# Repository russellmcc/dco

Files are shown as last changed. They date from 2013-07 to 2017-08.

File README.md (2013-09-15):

This is a simple design for an incredibly cost-sensitive DCO module for eurorack format modular synthesizers.

Firmware was written with Arduino, using @brendan0powers's [Xmegaduino fork](https://github.com/brendan0powers/Xmegaduino).  To program, use the following avrdude command from the `firmware` directory, using an [avrismpmkII](http://www.atmel.com/tools/AVRISPMKII.aspx):

    avrdude -patxmega32a4 -cavrispmkII -Pusb -Uflash:w:firmware.hex

This work is licensed under a [Creative Commons Attribution-ShareAlike 3.0 Unported License.](http://creativecommons.org/licenses/by-sa/3.0/deed.en_US)

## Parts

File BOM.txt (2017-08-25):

Connectors:
1x MO4x2         Connection header
1x M04x2  female Connection jack
1x MO3x2     AVR PDI header
1x MO8x2     Eurorack power connector
3x erthenvar jacks

Semiconductors
1x QFP44     Atmel XMega 32A4U (TQFP)         (U1)
1x SOT23     MMBT3904 NPN Transistor          (Q101)
1x SOT223    MIC2920A-3.3BS regulator         (IC301)
2x SOIC-8    LF353D op amp                    (IC101, IC201)
2x SOD-323   5V zener diode                   (D301, D301)

Potentiometers
3x PDB12 100K PCB mount panel pot (PDB12-H4251-104BF)
1x 5mm   100K thru-hole trimpot (N6-L50T0C-100K)

Resistors
1x 0805 1    Resistor 5% (R102)
1x 0603 1K   Resistor 5% (R110)
5x 0603 10K  Resistor 5% (R101, R107, R108, R301, R302)
1x 0603 27K  Resistor 5% (R205)
1x 0603 33K  Resistor 5% (R208)
1x 0603 33K  Resistor 1% (R209)
1x 0603 51K  Resistor 1% (R207)
5x 0603 100K Resistor 5% (R104, R105, R202, R203, R206)
1x 0603 100K Resistor 1% (R201)
1x 0603 200K Resistor 5% (R103)
1x 0603 300K Resistor 5% (R109)
1x 0603 1M   Resistor 5% (R106)
1x 0603 1.5M Resistor 5% (R204)

Capacitors
1x 0603 220pF C0G capacitor      (C101)
3x 0603 .1uF  X7R capacitor      (C302, C303, C305)
1x 1210 .1uF  PPS capacitor      (C102)
2x 0805 1uF   X7R capacitor      (C103, C301) 
1x 1205 10uF  X5R capacitor      (C304)

Other TODOs- 
Make sure C103 does not have too much distortion during testing

Mouser link to project:
http://www.mouser.com/ProjectManager/ProjectDetail.aspx?AccessID=DEDAD2A673

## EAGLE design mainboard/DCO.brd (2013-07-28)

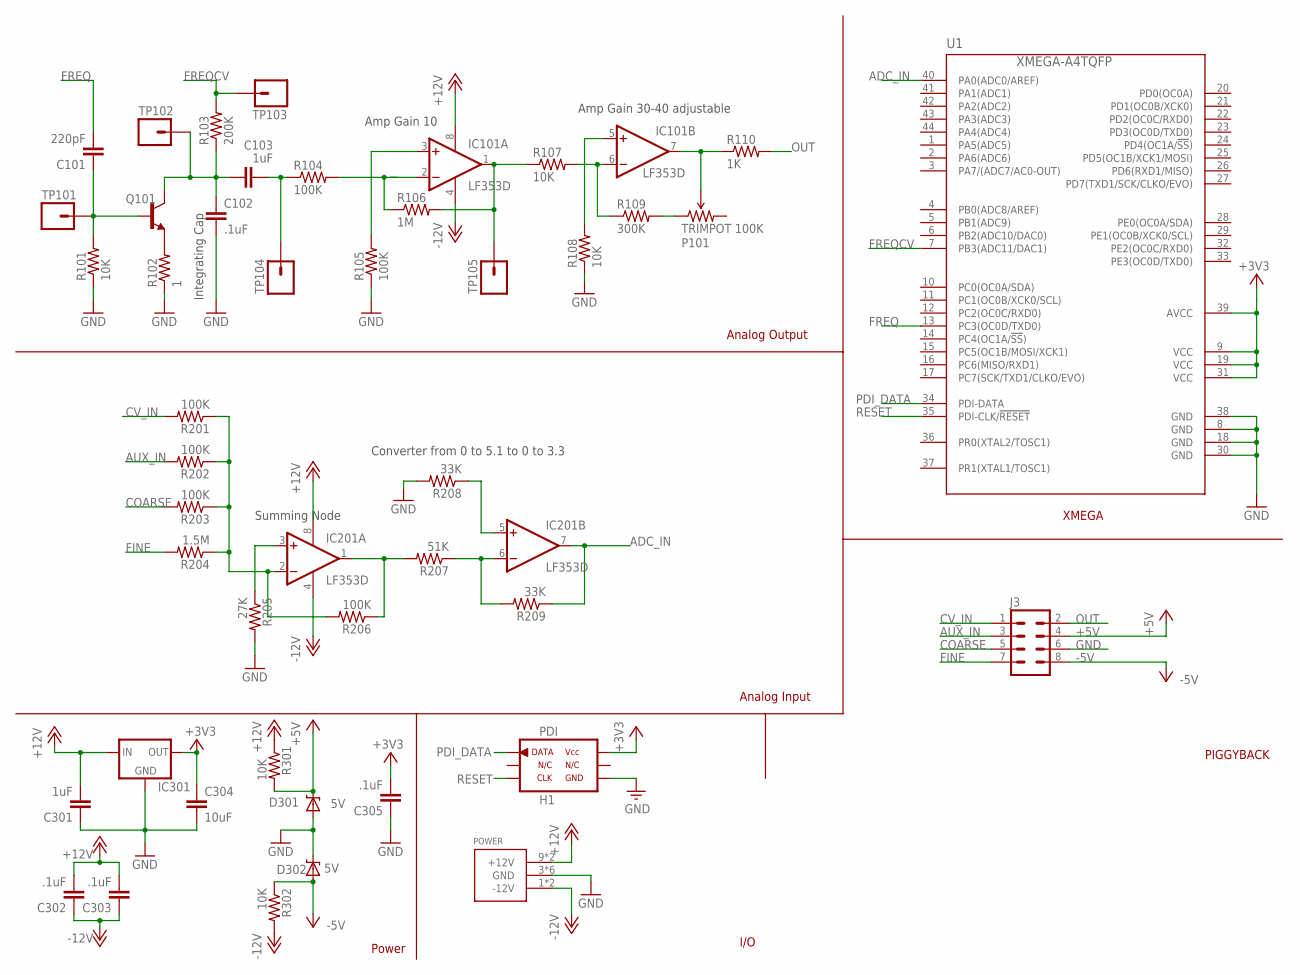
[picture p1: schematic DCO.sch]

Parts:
C101: 220pF; 0603-CAP
C102: .1uF; 1210
C103, C301: 1uF; 0805
C302, C303, C305: .1uF; 0603-CAP
C304: 10uF; 1206
D301, D302: 5V; SOD-323
H1: PDI; AVR_ISP_6
IC101, IC201: LF353D; SO08
IC301: V_REG_MIC2920; SOT223
J3: M04X2; 2X4
P101: TRIMPOT 100K; TRIM_POT_PTH
POWER: POWER_SIMPLE16; POWER_16
Q101: TRANSISTOR_NPNSOT23; SOT23
R101, R107, R108, R301, R302: 10K; 0603-RES
R102: 1; 0805
R103: 200K; 0603-RES
R104, R105, R201, R202, R203, R206: 100K; 0603-RES
R106: 1M; 0603-RES
R109: 300K; 0603-RES
R110: 1K; 0603-RES
R204: 1.5M; 0603-RES
R205: 27K; 0603-RES
R207: 51K; 0603-RES
R208, R209: 33K; 0603-RES
TP101, TP102, TP103, TP104, TP105: M01PTH; 1X01
U1: XMEGA-A4TQFP; TQFP44

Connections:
+3V3: C304.1, C305.2, H1.P$2 (VCC_IO), IC301.3 (OUT), U1.9 (VCC), U1.19 (VCC), U1.31 (VCC), U1.39 (AVCC)
+5V: D301.1 (C), J3.4, R301.2
+12V: C301.2, C302.2, C303.2, IC101.8 (V+), IC201.8 (V+), IC301.1 (IN), POWER.9 (+12V), POWER.10 (+12V), R301.1
-5V: D302.2 (A), J3.8, R302.1
-12V: C302.1, C303.1, IC101.4 (V-), IC201.4 (V-), POWER.1 (-12V), POWER.2 (-12V), R302.2
ADC_IN: IC201.7 (OUT), R209.1, U1.40 (PA0(ADC0/AREF))
AUX_IN: J3.3, R202.2
COARSE: J3.5, R203.2
CV_IN: J3.1, R201.2
FINE: J3.7, R204.2
FREQ: C101.2, U1.13 (PC3(OC0D/TXD0))
FREQCV: R103.2, TP103.1, U1.7 (PB3(ADC11/DAC1))
GND: C102.2, C301.1, C304.2, C305.1, D301.2 (A), D302.1 (C), H1.P$6 (GND), IC301.2 (GND), J3.6, POWER.3 (GND), POWER.4 (GND), POWER.5 (GND), POWER.6 (GND), POWER.7 (GND), POWER.8 (GND), R101.1, R102.1, R105.1, R108.1, R205.2, R208.2, U1.8 (GND), U1.18 (GND), U1.30 (GND), U1.38 (GND)
unnamed: C102.1, C103.1, Q101.3 (C), R103.1, TP102.1
unnamed: C101.1, Q101.1 (B), R101.2, TP101.1
unnamed: IC101.6 (-IN), R107.2, R109.1
unnamed: Q101.2 (E), R102.2
unnamed: C103.2, R104.1, TP104.1
unnamed: IC201.3 (+IN), R205.1
unnamed: IC101.3 (+IN), R105.2
unnamed: IC101.5 (+IN), R108.2
unnamed: IC101.7 (OUT), P101.2 (WIPER), R110.1
unnamed: P101.1 (CCW), R109.2
unnamed: IC101.1 (OUT), R106.2, R107.1, TP105.1
unnamed: IC201.1 (OUT), R206.1, R207.2
unnamed: IC201.6 (-IN), R207.1, R209.2
unnamed: IC201.5 (+IN), R208.1
OUT: J3.2, R110.2
PDI_DATA: H1.P$1 (DATA), U1.34 (PDI-DATA)
R104: IC101.2 (-IN), R104.2, R106.1
R205: IC201.2 (-IN), R201.1, R202.1, R203.1, R204.1, R206.2
RESET: H1.P$5 (CLK), U1.35 (PDI-CLK/!RESET)

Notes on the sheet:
Integrating Cap
Amp Gain 10
Amp Gain 30-40 adjustable
Summing Node
Converter from 0 to 5.1 to 0 to 3.3
Analog Output
Analog Input
Power
I/O
XMEGA
PIGGYBACK

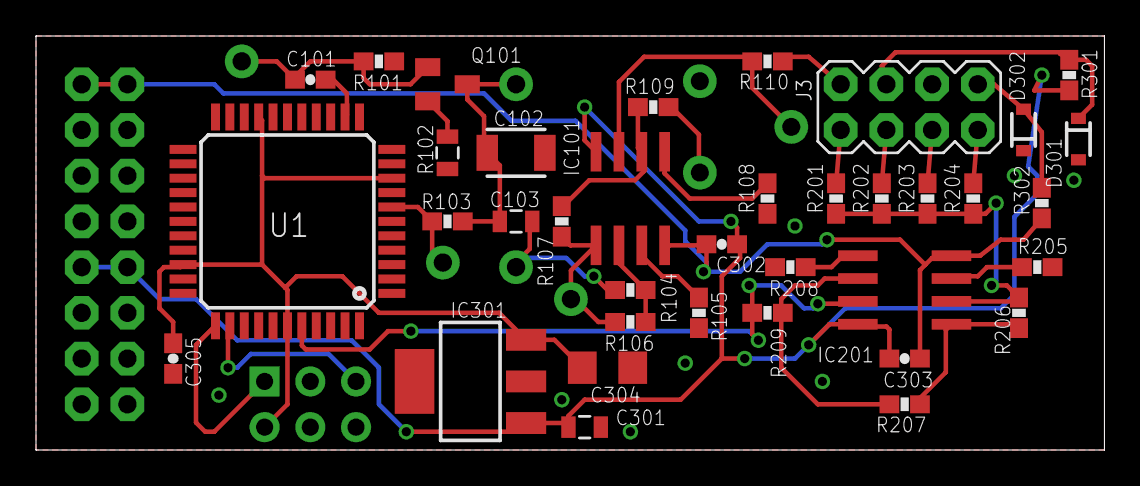
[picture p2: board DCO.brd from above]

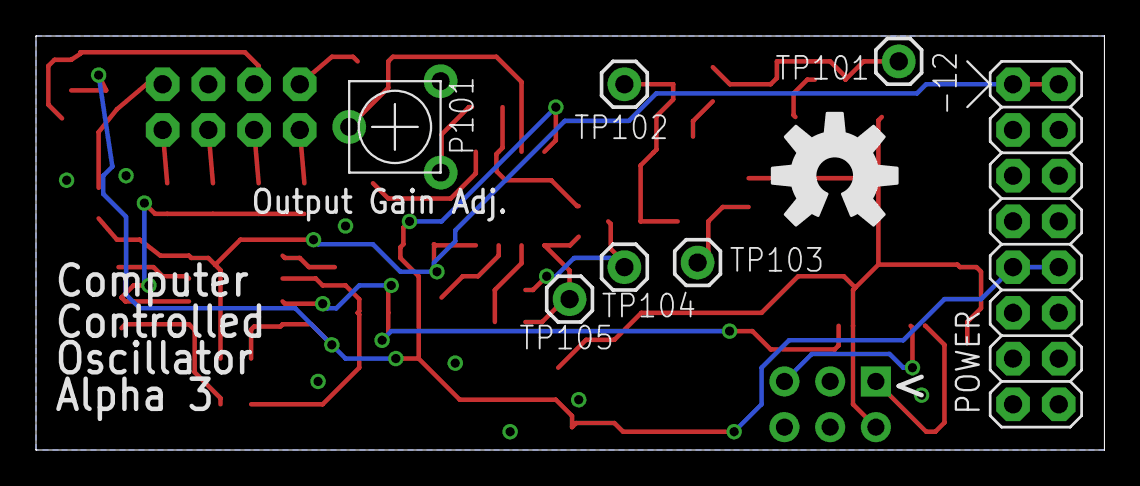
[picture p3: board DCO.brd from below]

Board: 2 copper layers, 59.4 x 23.0 mm, 46 parts (9 on the bottom side), 32 nets.

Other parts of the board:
U$1: OSHW-LOGO-L

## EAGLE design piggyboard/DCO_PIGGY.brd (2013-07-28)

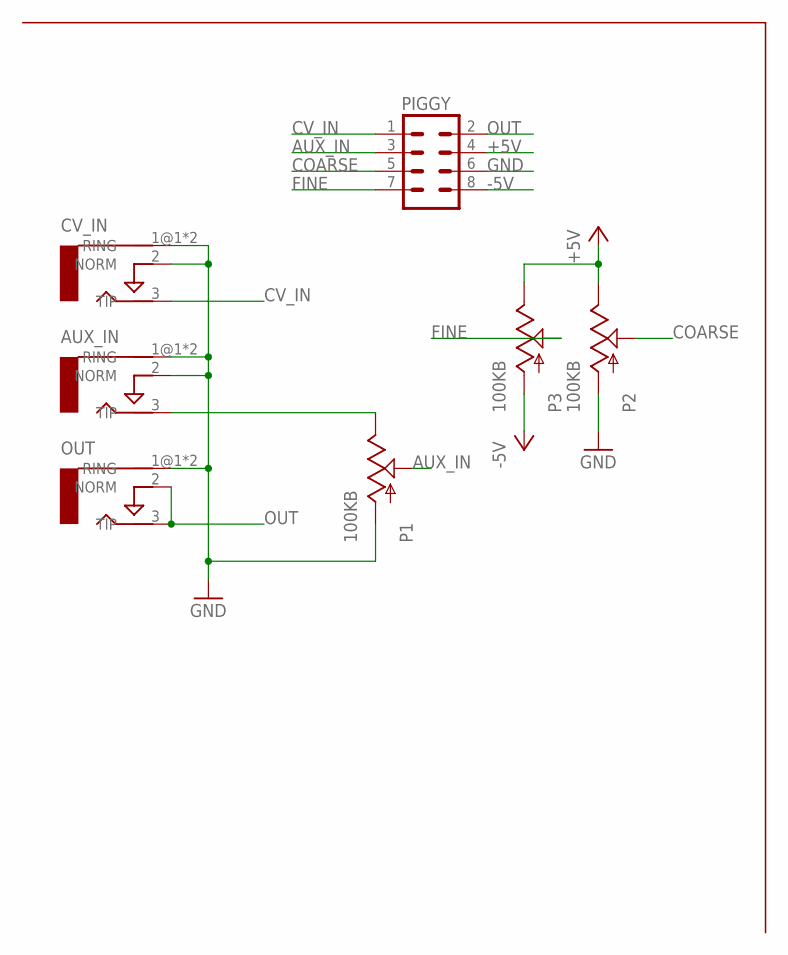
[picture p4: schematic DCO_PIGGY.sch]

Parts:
AUX_IN: AUDIO-JACKERTHENVAR; ERTHENVAR-JACK
CV_IN: AUDIO-JACKERTHENVAR; ERTHENVAR-JACK
OUT: AUDIO-JACKERTHENVAR; ERTHENVAR-JACK
P1, P2, P3: 100KB; PDB12
PIGGY: M04X2; 2X4

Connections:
+5V: P2.3 (E), P3.3 (E), PIGGY.4
-5V: P3.1 (A), PIGGY.8
AUX_IN: P1.2 (S), PIGGY.3
COARSE: P2.2 (S), PIGGY.5
CV_IN: CV_IN.3 (TIP), PIGGY.1
FINE: P3.2 (S), PIGGY.7
GND: AUX_IN.1@1 (RING), AUX_IN.1@2 (RING), AUX_IN.2 (NORM), CV_IN.1@1 (RING), CV_IN.1@2 (RING), CV_IN.2 (NORM), OUT.1@1 (RING), OUT.1@2 (RING), P1.1 (A), P2.1 (A), PIGGY.6
unnamed: AUX_IN.3 (TIP), P1.3 (E)
OUT: OUT.2 (NORM), OUT.3 (TIP), PIGGY.2

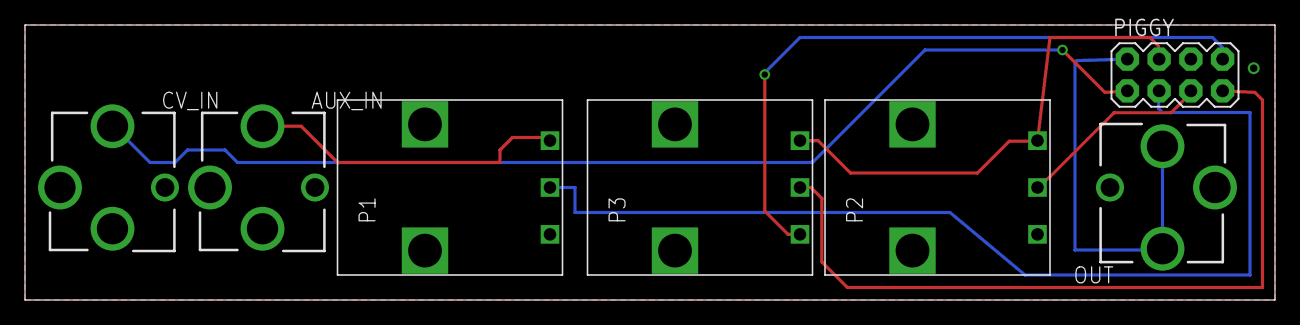
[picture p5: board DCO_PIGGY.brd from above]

Board: 2 copper layers, 100.0 x 22.0 mm, 7 parts (0 on the bottom side), 9 nets.

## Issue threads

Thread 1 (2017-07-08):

Still relevent?

dwhacks, 2017-07-08:
How does this project work? Im looking for a DIY DCO project for my eurorack and stumbled upon this but noticed its a bit older. Are you happy with it? should I get the boards fabbed and build a couple up?

russellmcc, 2017-07-08:
Great question!  I would say I am not happy with this iteration of the design.  It seems to be *very* sensitive to power supply fluctuations.  I'm actually hoping to return to this project this year to fix it up for switching power supplies.  It did work great when I had an expensive linear supply, though.

If you have some analog chops, I'd definitely be open to help cleaning up the analog path for better power supply rejection.  I think the digital code and DCO core is pretty solid.

I'm not aware of another juno 6/60/106-style DCO DIY eurorack project.  I'm currently working on an alpha juno "DCO" (works with direct digital synthesis at 6MHz for lower aliasing), which should be done in a few months.

You might want to look at the mutable instrument braids or the "microbraids" OLED variant if you're looking for a digital/analog DIY project - of course this isn't the same as the juno-style DCO, though.

dwhacks, 2017-07-08:
Thanks!
I have looked at the microbraids and also the Neutron Orgone Accumulator as options, but this one peaked my interest more being smaller and more unique (in my opinion).

Im not sure what you mean by "analog chops".

russellmcc, 2017-07-08:
I just meant "ability to do analog design well" :-)

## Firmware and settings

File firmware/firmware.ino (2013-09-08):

#include "MultiTone.h"
#include "stdint.h"
#include "table.h"

uint32_t running_average; //1.15 format

// optional lowpass filter
const float alphaFloat = 0;  // CHANGE THIS TO ADD PORTAMENTO/TUNING STABILITY.
                             // higher the value, more portamento and more stability.
const uint32_t alpha = 0xFFFF * alphaFloat; //0.16
const uint32_t oneMinusAlpha = 0xFFFF * (1 - alphaFloat); //0.16

// we need 12 bits of ADC
extern "C" int analogRead12(unsigned char pin);

void EnableDFLL()
{
  // enable the 32KHz clock
  OSC.CTRL |= OSC_RC32KEN_bm;

  // wait for stability
  while(not (OSC.STATUS & OSC_RC32KRDY_bm));

  // enable DFLL for extra power drain and accuracy.
  OSC.DFLLCTRL = (OSC.DFLLCTRL & ~OSC_RC32MCREF_gm) | OSC_RC32MCREF_RC32K_gc;
  DFLLRC32M.CTRL |= DFLL_ENABLE_bm;
  
  // wait for 32MHz stability.
  while(not (OSC.STATUS & OSC_RC32MRDY_bm));
}

void SetupTimers()
{
  // TCC1 is the prescaler timer, triggering events on EVCH6
  TCC1.CTRLA = TC_CLKSEL_DIV1_gc;
  TCC1.CTRLB = (TCC1.CTRLB & ~TC0_WGMODE_gm) | TC_WGMODE_SINGLESLOPE_gc;
  TCC1.PERBUF = 0x3; // every fourth clock
  
  // set it up to trigger EVCH6 events whenever TCC1 overflows
  EVSYS.CH6MUX = EVSYS_CHMUX_TCC1_OVF_gc;
  
  // TCC0D is the output timer (pin D13)
  pinMode(13, OUTPUT);
  TCC0.CTRLA = TC_CLKSEL_EVCH6_gc;
  TCC0.CTRLB = (TCC0.CTRLB & ~TC0_WGMODE_gm) | TC_WGMODE_SINGLESLOPE_gc;
  TCC0.CTRLB |= TC0_CCDEN_bm;
  TCC0.PERBUF = 0x8FFF; // half-way
  TCC0.CCDBUF = 10;
}

void setup()
{
  // use the arduino library calls to 
  // get everything into the right mode
  // we'll later use the setup done here
  // to just do fast writes to the underlying registers.
  analogWrite(A0, 12);
  EnableDFLL();
  SetupTimers();
  running_average = analogRead12(8) << 3; //1.15
}

void UpdateTimers(uint16_t input)
{
  uint16_t preScale = pgm_read_word(&kHi[input]);
  uint16_t period = pgm_read_word(&kLo[input]);

  // wait until all timers are stabilized
  while ((TCC0.CTRLGSET & (TC0_PERBV_bm | TC0_CCDBV_bm)) &&
         (TCC1.CTRLGSET & (TC1_PERBV_bm))){}
  TCC0.PERBUF = period;
  TCC0.CCDBUF = period >> 2;
  TCC1.CTRLFSET = TC1_LUPD_bm;
  TCC1.PERBUF = preScale;

  while (TCC0.CTRLGSET & TC0_PERBV_bm){}
  TCC1.CTRLFCLR = TC1_LUPD_bm;

}

void loop()
{
  uint16_t input = analogRead12(8); //4.12
  running_average = alpha * running_average >> 16;
  running_average += (oneMinusAlpha * (input << 3)) >> 16;
  input = running_average >> 3;
  input &= 0xFFF; // 12 bit.

  // A0 is DACB CH1
  if ( (DACB.STATUS & DAC_CH1DRE_bm) )
    DACB_CH1DATA = pgm_read_word(&kAmps[input]) & 0x0FFF;
  
  UpdateTimers(input);
}

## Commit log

2012-12-26 Changed isolation settings on ground planes for piggy back board
    [DCO_PIGGY.brd]
2012-12-28 Re-laid out board, no routing
    [DCO.brd, DCO.sch]
2012-12-28 added BOM
2012-12-29 updated BOM after sourcing from mouser
2012-12-29 edited schematic parts after sourcing from mouser, initial board layout.
    [DCO.brd, DCO.sch]
2012-12-29 brendan said it was a good idea to add a ground via near the decoupling cap for the micro
    [DCO.brd, DCO.sch]
2013-01-04 Another attempt to layout DCO.
    [DCO.brd, DCO.sch]
2013-01-04 Adjusted labels on top of board
    [DCO.brd]
2013-01-04 adjusted labels on bottom of board
    [DCO.brd]
2013-01-11 fix for a messed up output jack on the piggy board
    [DCO_PIGGY.brd, DCO_PIGGY.sch]
2013-01-27 better hole placement
2013-02-07 fix for BOM malfunction
2013-02-12 Fixed Silkscreens
    [DCO.brd]
2013-02-15 fixed footprint
    [DCO_PIGGY.brd, DCO_PIGGY.sch]
2013-03-01 added soldermask SVG
2013-03-01 oops - border was messed up on soldermask.
2013-06-09 rerouted, switched to TQFP xmega
    [DCO.brd, DCO.sch]
2013-06-09 edited labels
    [DCO.brd, DCO.sch]
2013-07-28 Fixed design flaw - these resistors should be 10K
    [DCO.brd, DCO.sch]
2013-07-28 Fix for design flaw - fine pitch control was attached backwards.
    [DCO.brd, DCO_PIGGY.brd, DCO_PIGGY.sch]
2013-08-28 added ability to track maximum errors in tablegen
2013-08-28 switched to using a 32-bit timer
2013-09-08 Two fixes: first, hold off on updating the prescale until after the least significant timer has updated. This should significantly reduce distortion when switching prescales. Second, don't use 0 as a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
    [firmware.ino]
2013-09-08 Added tuning constant to haskell generator, tuned my board.
    Added comment about how to use the digital filter in firmware.ino
    Version 1.0

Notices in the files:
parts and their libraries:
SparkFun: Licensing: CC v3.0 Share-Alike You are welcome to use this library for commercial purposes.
